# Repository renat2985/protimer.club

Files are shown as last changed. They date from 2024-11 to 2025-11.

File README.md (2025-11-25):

[🇷🇺 Русская версия документации здесь](https://github.com/renat2985/protimer.club/blob/main/README_RU.md)

#  Your Personal Performance Archive!

**ProTimer.club** is a modern solution for athletes, offering precise time measurement, result recording, and analysis to enhance training efficiency. Our devices are suitable for various sports and competitions, providing convenience, accuracy, and cloud integration.

You can log in with a demo profile and explore all the website features right now: [https://protimer.club/login#demo](https://protimer.club/login#demo)

    Email: demo@protimer.club
    Password: demo 

Here’s a link showcasing how you can share your page and display your results to anyone, even those who are not registered on the site: https://protimer.club/share/MzlLRDlaT1hnMTNaeEVZbnFSTTNHUT09

<p align="center">
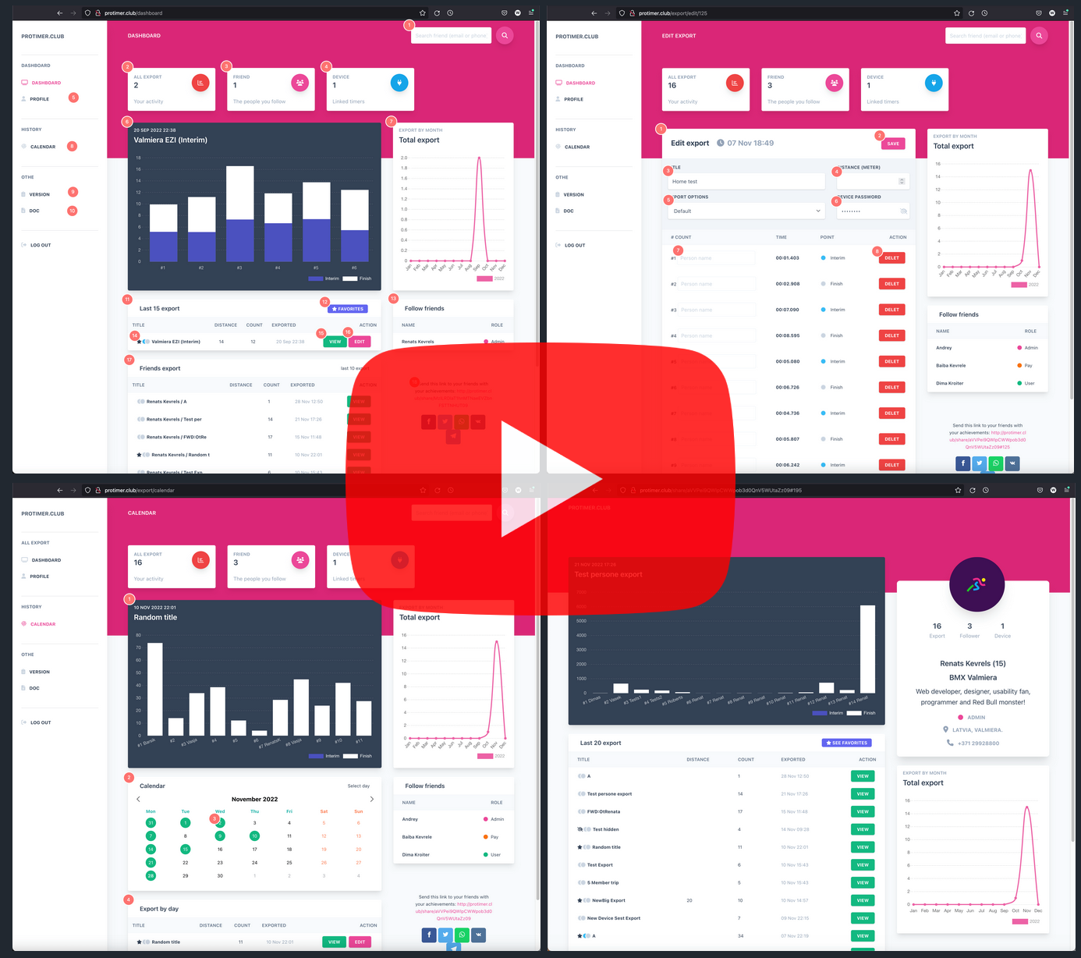
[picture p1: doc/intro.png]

</p>

## Key Features

  - **Precise time measurement:** Accuracy up to 0.003 seconds.
  - **Ease of use:** Simple system setup accessible to everyone.
  - **Cloud integration:** Export data to ProTimer.club for storing and analyzing training history.
  - **Social network:** Share achievements and follow the progress of your friends.
  - **Versatility:** Support for various modes and features for team and individual training.

_Learn more about the features [here](https://protimer.club/en/doc)._

---

## How It Works

### Master Point — The main module of the system that manages the ProTimer network.

1. **Power On and Connect:**

    - Turn on the Master Point; it will create a Wi-Fi network "ProTimer.club".
    - Connect to this network using your smartphone, tablet, or laptop.

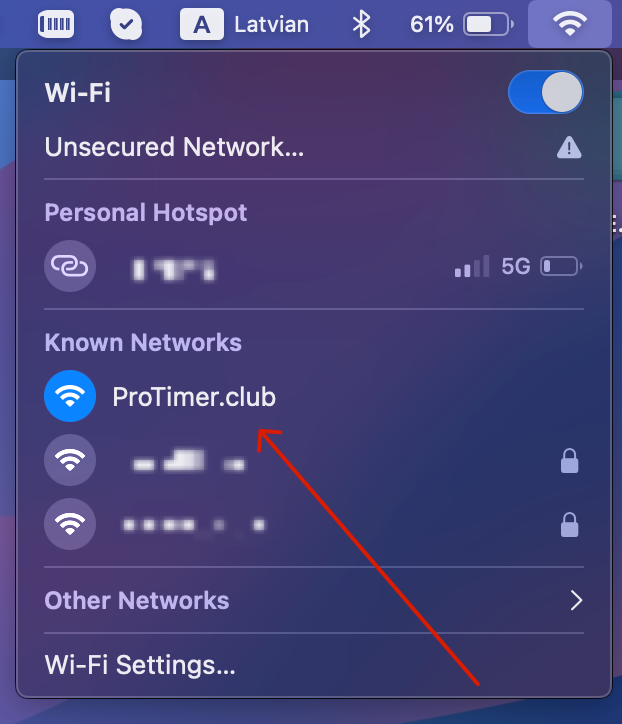
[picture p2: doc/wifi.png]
        

2. **Access the Control Interface:**

    - Open a browser and enter the address `http://192.168.4.1` to access the web interface.
    - Use the interface to configure modes, control the timer, and export data.

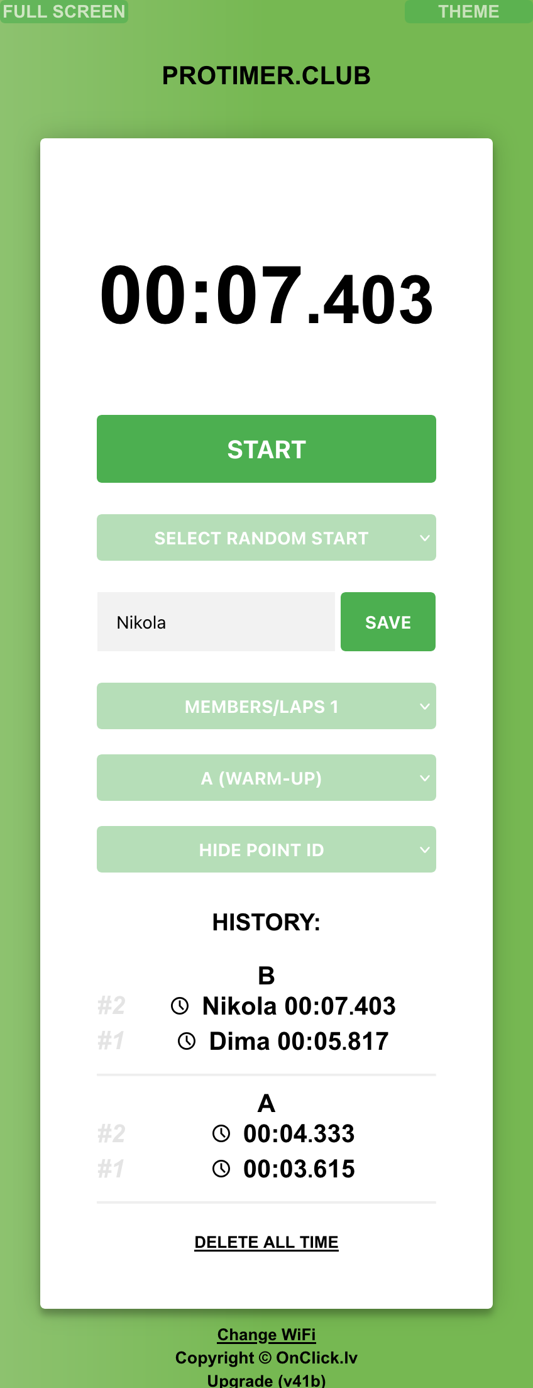
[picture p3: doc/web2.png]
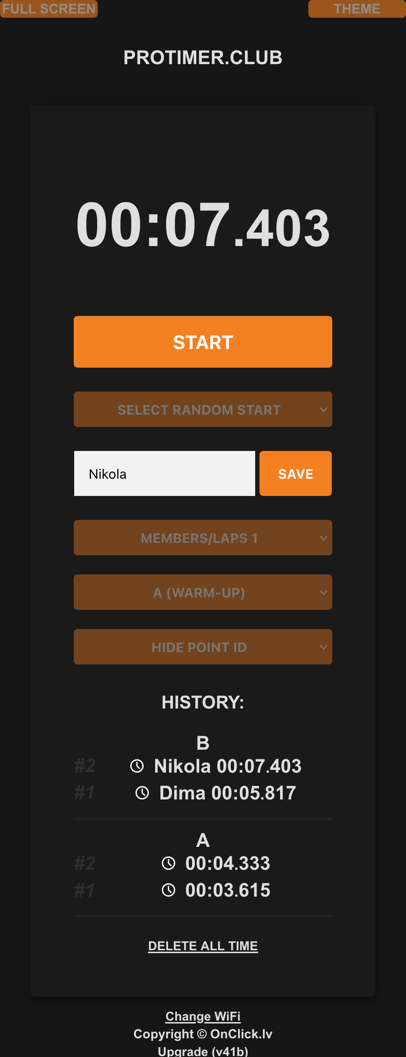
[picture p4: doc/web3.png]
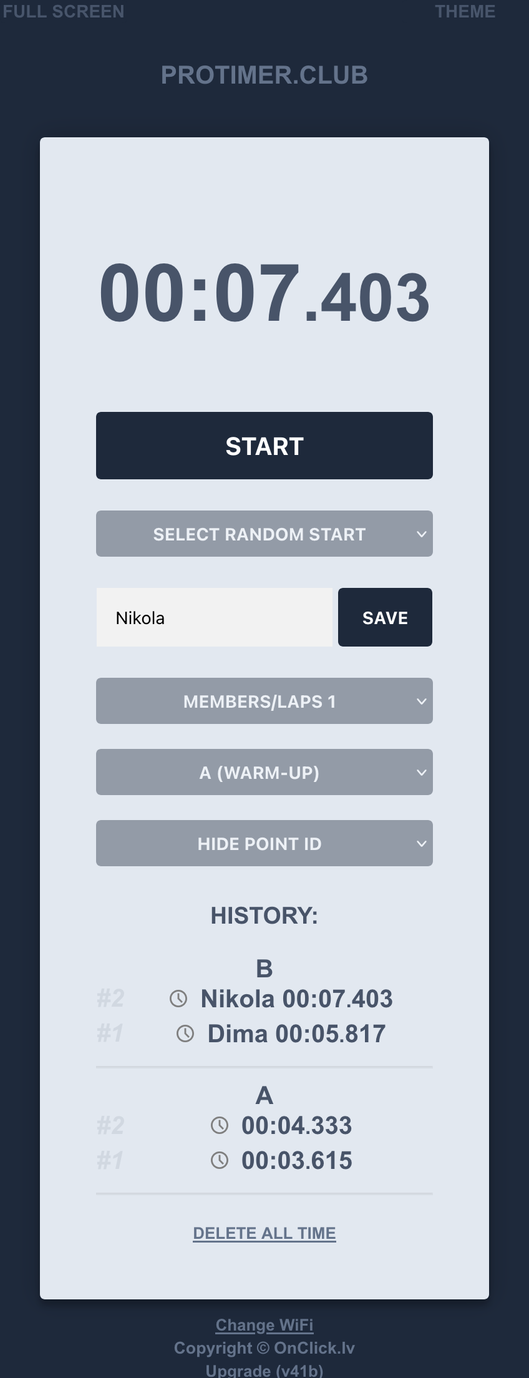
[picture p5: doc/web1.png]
          

3. **Connecting to the Router:**

    - During the first setup, the device will ask for your home Wi-Fi network name and password. This is required for automatic data export to the cloud.
    - Once configured, the device will automatically connect to the specified router every time it is powered on and upload your data to the ProTimer.club cloud.
    - This means that after your training session, you just need to turn on the device for a few seconds — it will connect to Wi-Fi and export all your results automatically. Simple and convenient!

    **Device Display:**

       

    _Read more details [here](https://protimer.club/en/doc#doc5)._

### Point PRO — An additional module that serves as a start, intermediate, or finish point.

1. **Operating Modes:**

    - **Start:** Starts the timer when the beam between the sensor and the reflector is crossed.
    - **Intermediate:** Captures split times at intermediate points.
    - **Finish:** Stops the timer when the beam is crossed.

2. **Connection to Master Point:**

    - Point PRO automatically synchronizes with Master Point within a range of up to 250 meters.
    - Use the built-in Point PRO display to check the connection and select the operating mode.

3. **Point PRO Features:**

    - Equipped with a display for real-time status updates.
    - Supports multiple channels for simultaneous use of multiple sets on one track.
    - High measurement accuracy of up to 0.003 seconds.

    **Device Display:**

      

    _Read more details [here](https://protimer.club/en/doc#doc5)._

#### ⚠️ Point PRO and Master Point work together, giving athletes and coaches full control over training sessions with precise results.

---

## Contact

You can build the device yourself or ask us to do it for you. To order a ready-made device, contact us via [Telegram](https://t.me/ESPiotDevice), [WhatsApp](https://chat.whatsapp.com/H7IpCrilF00H3wGbANnA1i), [Skype](https://skype:renat2985?chat), or [Discord](https://discord.gg/3986vwEdf5).

Ready-made equipment kits with customization options and additional modules are also available on our website.

---

## Connection Diagram

You can build the device using NodeMCU ESP8266 or Wemos ESP8266. This diagram applies to both the Master and Point (PRO) devices. Choose the appropriate software link below for installation.

On the NodeMCU board, the Flash button performs the same functions as the external button connected to D3. If needed, you can use it instead of the external button.

## Pinout Configuration

| **Pin** | **GPIO** | **Function** |
|---|---|---|
| **D1**  | GPIO5 | SCK (Display) |
| **D2**  | GPIO4 | SDA (Display) |
| **RX**  | GPIO3 | IR or LASER Sensor (NPN NO)|
| **D3**  | GPIO0 | Button |
| **D7**  | GPIO13 | Active Buzzer (optional) |
| **D6**  | GPIO12 | Passive Buzzer (optional)  |
| **D0**  | GPIO16 | [GATE Relay](https://github.com/renat2985/protimer.club/discussions/6) (optional) |

### [E3Z-R61, NPN NO](https://www.aliexpress.com/item/1005004123351251.html) (max 2-3m "gates", IR sensor)

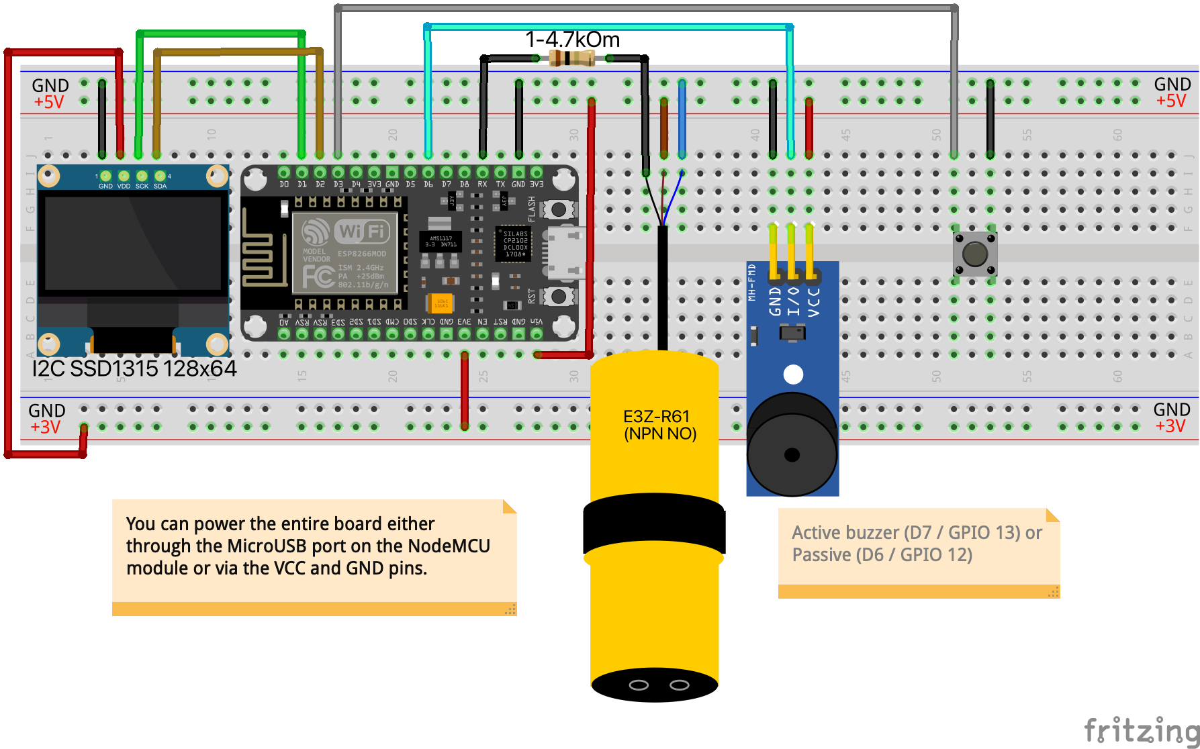
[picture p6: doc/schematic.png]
Connection Diagram
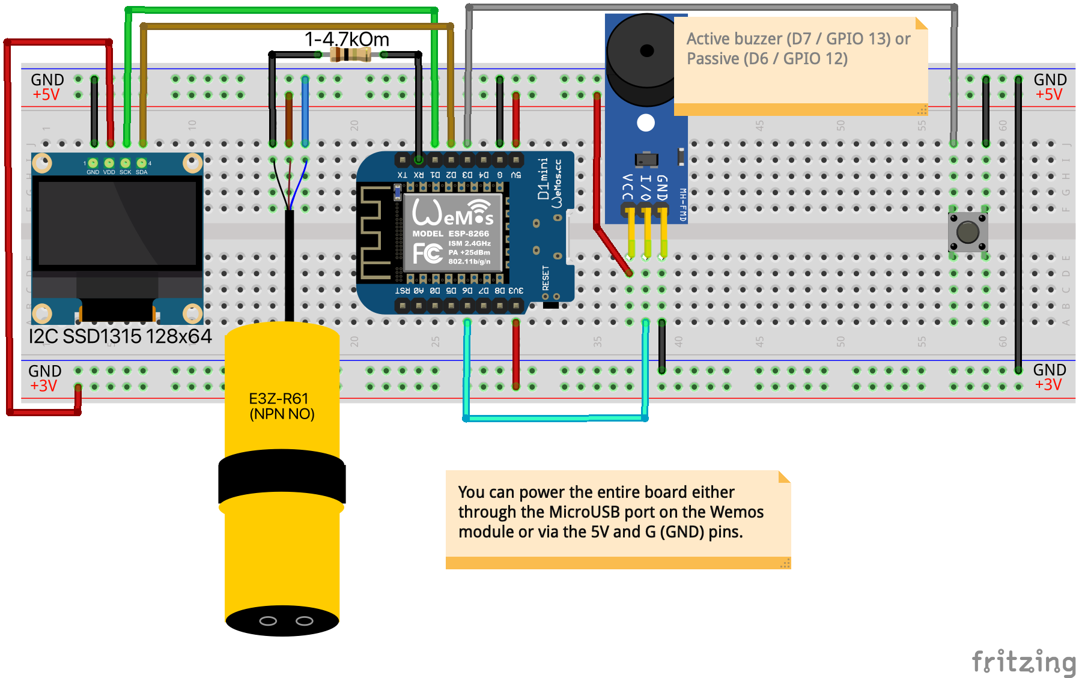
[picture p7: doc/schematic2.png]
Connection Diagram 2
 

### [E3Z-LAS-R8, NPN NO](https://www.aliexpress.com/item/1005005879848648.html) (max 7-8m "gates", Laser sensor) 

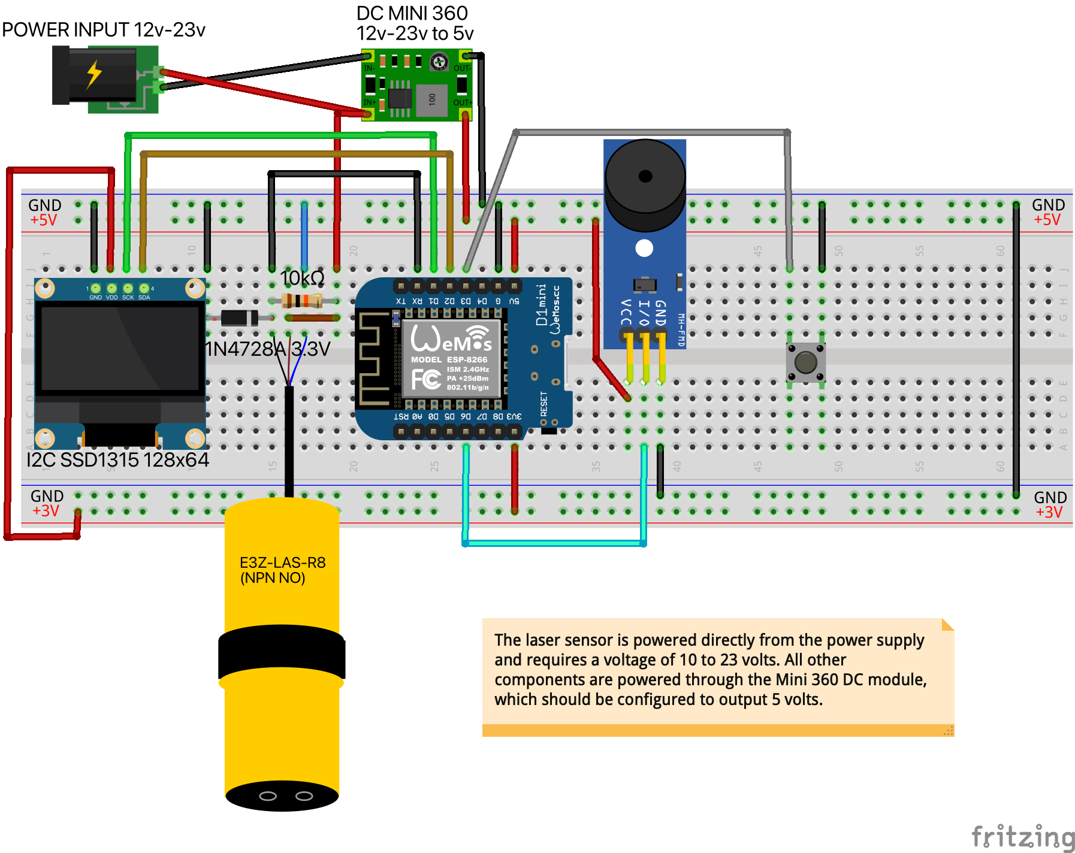
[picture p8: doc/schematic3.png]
Connection Diagram 3
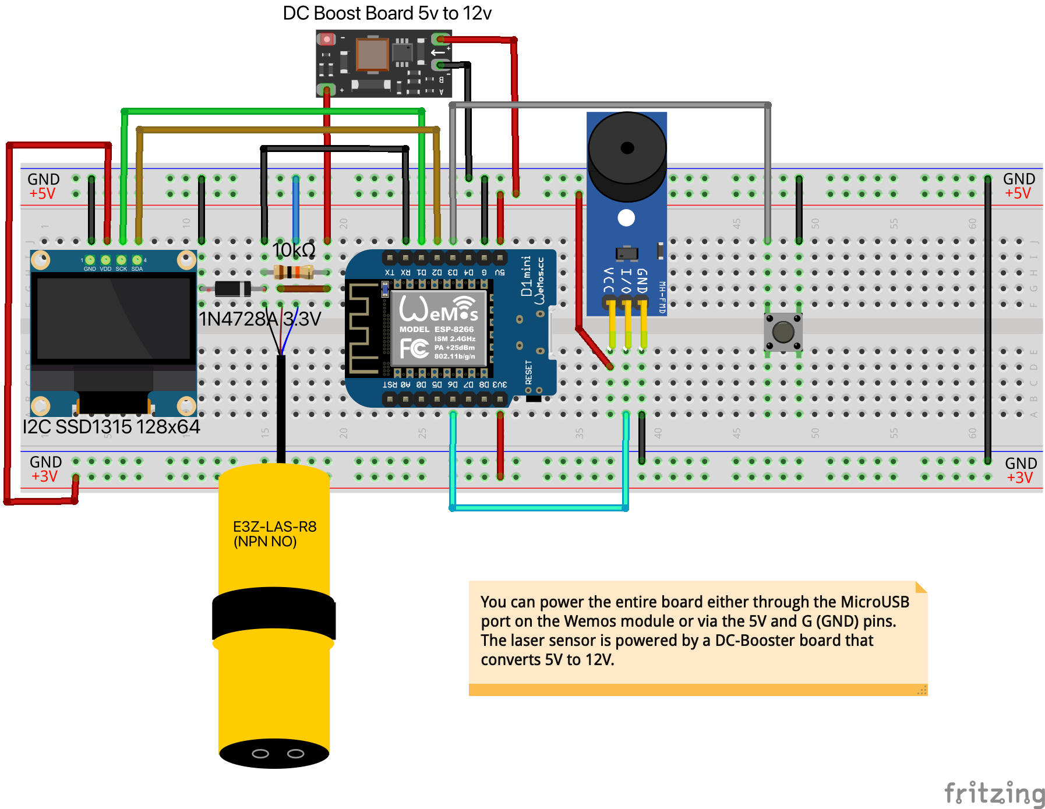
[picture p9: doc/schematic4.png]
Connection Diagram 4
 

## [Soldering Wemos, step by step](https://github.com/renat2985/protimer.club/discussions/10)

E3Z-R61

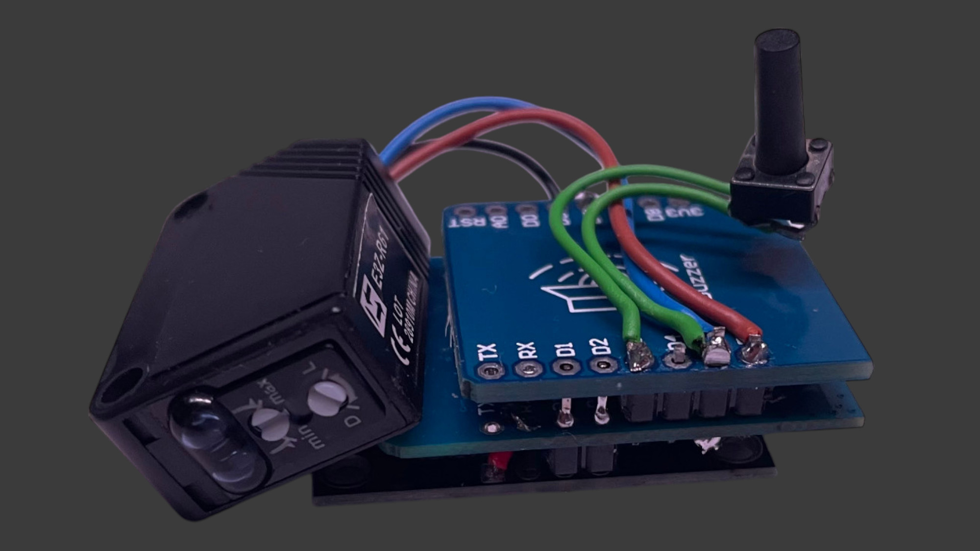
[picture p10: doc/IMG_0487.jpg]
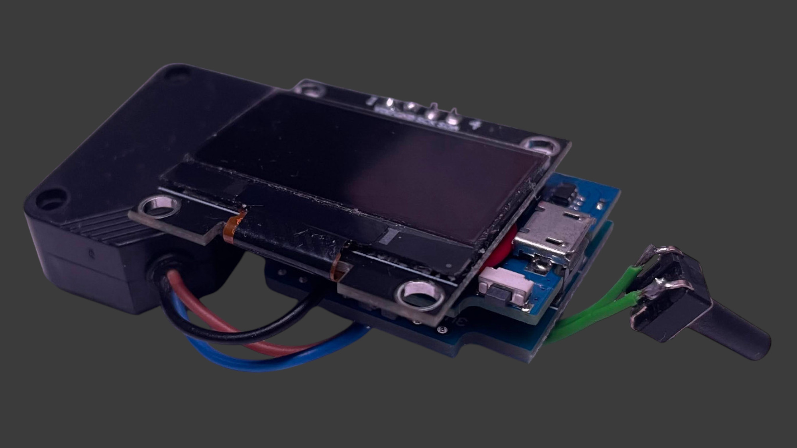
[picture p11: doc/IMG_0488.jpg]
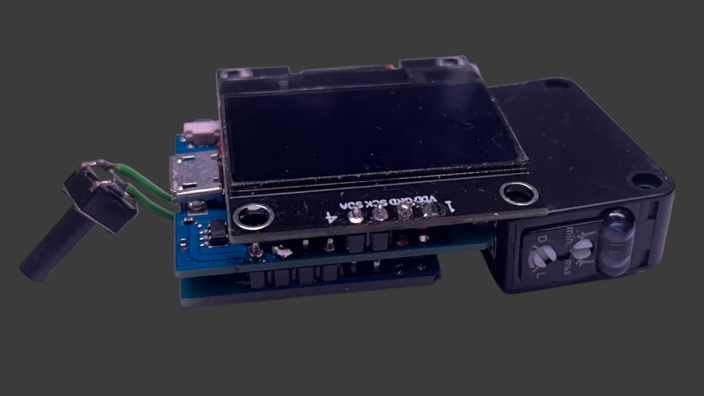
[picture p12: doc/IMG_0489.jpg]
  

E3Z-LAS-R8, NPN NO

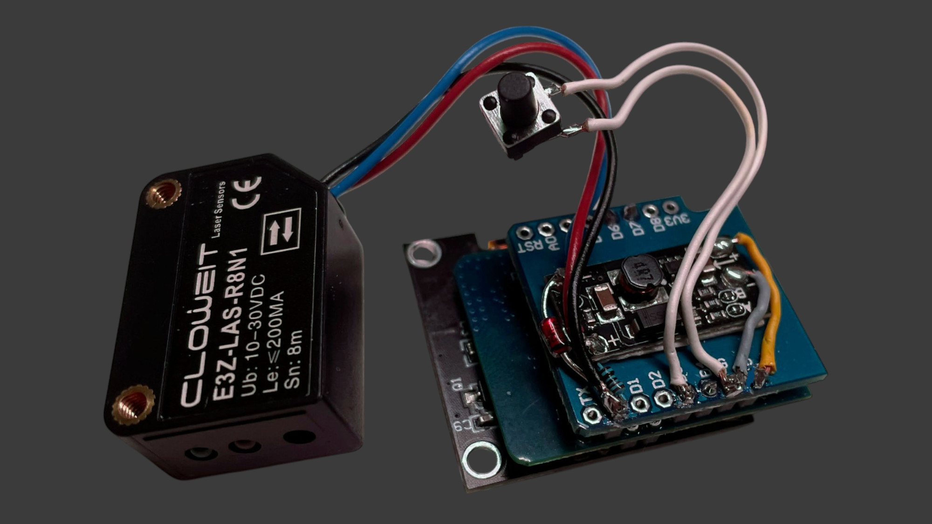
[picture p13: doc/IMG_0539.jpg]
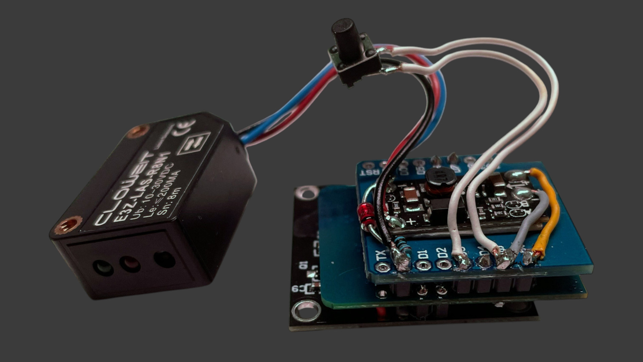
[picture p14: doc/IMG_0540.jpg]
 

## STL (STL Folder)

All these parts can be found and printed from the [stl folder](https://github.com/renat2985/protimer.club/tree/main/stl).

#### For IR Device: 
- [Cover Master](https://github.com/renat2985/protimer.club/blob/main/stl/%D1%81over-M-wemos-final-v3.stl), [Cover Point](https://github.com/renat2985/protimer.club/blob/main/stl/%D1%81over-P-wemos-final-v3.stl), [Box](https://github.com/renat2985/protimer.club/blob/main/stl/box-Laser-big-wemos-final-v3.stl).
- Design by Sergey K.: [Box and Cover(M)](https://github.com/renat2985/protimer.club/blob/main/stl/box_and_cover_M_by_SergeyKryzhkov.stl), 
[Box and Cover(P)](https://github.com/renat2985/protimer.club/blob/main/stl/box_and_cover_P_by_SergeyKryzhkov.stl).

#### For Laser Device: 
- [Cover Master](https://github.com/renat2985/protimer.club/blob/main/stl/%D1%81over-Laser-M-wemos-final-v3.stl), [Cover Point](https://github.com/renat2985/protimer.club/blob/main/stl/%D1%81over-Laser-P-wemos-final-v3.stl), [Box](https://github.com/renat2985/protimer.club/blob/main/stl/box-big-wemos-final-v3.stl).
- Design by Sergey K.: [Box and Cover(M)](https://github.com/renat2985/protimer.club/blob/main/stl/box_and_cover_Laser_M_by_SergeyKryzhkov.stl), 
[Box and Cover(P)](https://github.com/renat2985/protimer.club/blob/main/stl/box_and_cover_Laser_P_by_SergeyKryzhkov.stl).

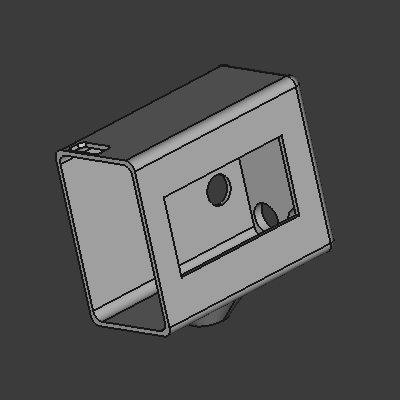
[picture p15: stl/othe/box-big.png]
Box big
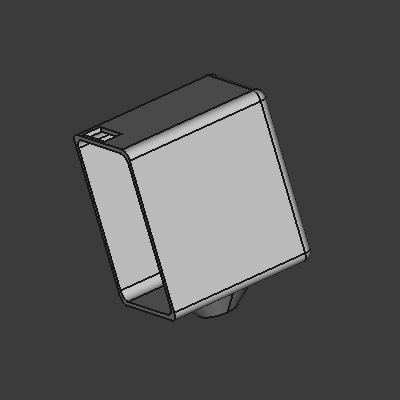
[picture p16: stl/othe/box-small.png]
Box small
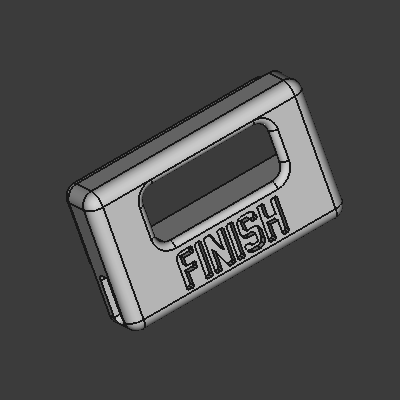
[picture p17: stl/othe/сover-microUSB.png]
Cover MicroUSB
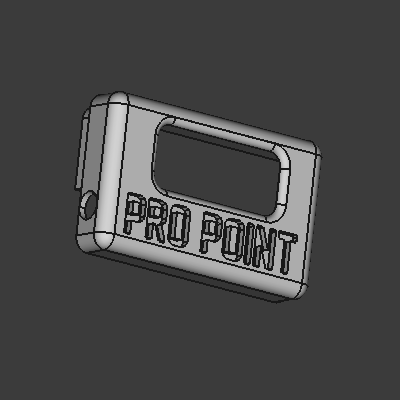
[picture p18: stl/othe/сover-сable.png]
Cover cable
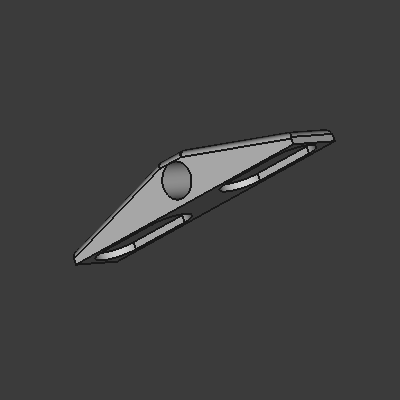
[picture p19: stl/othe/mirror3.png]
Reflector Holder 3
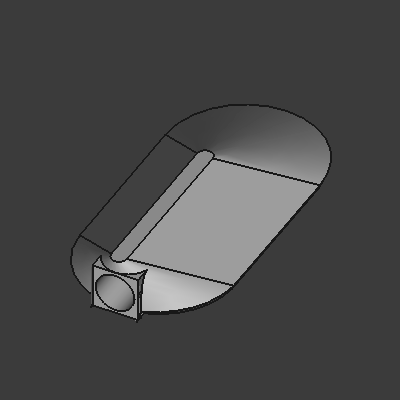
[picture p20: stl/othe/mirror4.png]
Reflector Holder 4
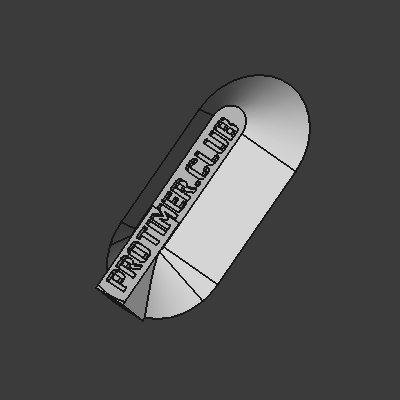
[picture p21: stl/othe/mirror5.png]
Reflector Holder 5
      

## From AliExpress.com

[E3Z-R61](https://www.aliexpress.com/item/1005004123351251.html) (2-3m, IR sensor) or [E3Z-LAS-R8, NPN NO](https://www.aliexpress.com/item/1005005879848648.html) (7-8m, Laser sensor) 

[Reflector TD-05](https://www.aliexpress.com/item/32990489226.html) (Better) or [Reflector TD-08](https://www.aliexpress.com/item/1005003584568763.html) (Worse)

[I2C SSD1315 128x64 1.3inch](https://www.aliexpress.com/item/1005004118377699.html)

[Wemos MINI ESP07](https://www.aliexpress.com/item/1005007081723288.html) (Suitable for STL case) or [NodeMCU ESP8266](https://www.aliexpress.com/item/1005004893349830.html) 

[Push Button Switch](https://www.aliexpress.com/item/1005004159746274.html) (6x6x8mm)

[Passive Buzzer Shield for WEMOS (D6 gpio)](https://www.aliexpress.com/item/1005007463046770.html) or [Active Buzzer Module for Arduino (D7 gpio)](https://www.aliexpress.com/item/1005005528181661.html)

Components for E3Z-LAS-R8, NPN NO

[Step-Down Board Mini 360](https://www.aliexpress.com/item/1005005995617482.html)

[Mini DC Boost Converter Board](https://www.aliexpress.com/item/1005007013856492.html)

[1N4728A 3.3V Zener Diode](https://www.aliexpress.com/item/4000297831644.html)

Other components 

[NFC Tag (NFC213, NFC215, NFC216)](https://www.aliexpress.com/item/1005002932627448.html)

[WiFi Antenna / IPEX Connector)](https://www.aliexpress.com/item/1005005743897181.html)

[Power Bank for 18650 Battery](https://www.aliexpress.com/item/1005002367815544.html)

[Mini Flexible Sponge Octopus Tripod](https://www.aliexpress.com/item/1005004177317958.html)

---

### 🚀 **Web Installer (Recommended)**  
Easily set up your device using the web installer. Choose the appropriate version and follow the instructions.

- **[Master Installer](https://renat2985.github.io/protimer.club/):** The main device that records the time.  
- **[Point Installer](https://renat2985.github.io/protimer.club/point.html):** An additional device that marks the finish line, checkpoints, or the start.  

### 🚀 **ESP8266 NodeMCU Flasher** 
- **[Download Installer](https://github.com/renat2985/protimer.club/raw/refs/heads/main/build/protimer.club.zip):** The archive contains two firmware versions: Master and Point.
    - To flash the Master version, check the box for upgrade128x64.bin.
    - To flash the Point version, uncheck upgrade128x64.bin and check upgrade_point128x64.bin.

    ❗ Important: You cannot check two boxes at the same time!

---

Instructions for users:

[DPF instructions (RUS)](https://github.com/renat2985/protimer.club/blob/main/doc/instruction.pdf)

[https://protimer.club/install/0000-0000](https://protimer.club/install/0000-0000) - you can change the WiFi password.

[https://protimer.club/install/en/0000-0000](https://protimer.club/install/ru/0000-0000) - you can change the language and the WiFi password.

---

### Acknowledgements
I would like to express my sincere gratitude to everyone who contributed to the project with their time, knowledge, and support. Thanks to you, it keeps getting better:
- Alex K.
- Sergey K.

## :battery: Donation

If you like this project, you can support us by buying a cup of coffee! ☕  

Donate Image

- **PayPal:** [https://www.paypal.me/RKevrels](https://www.paypal.me/RKevrels/5)

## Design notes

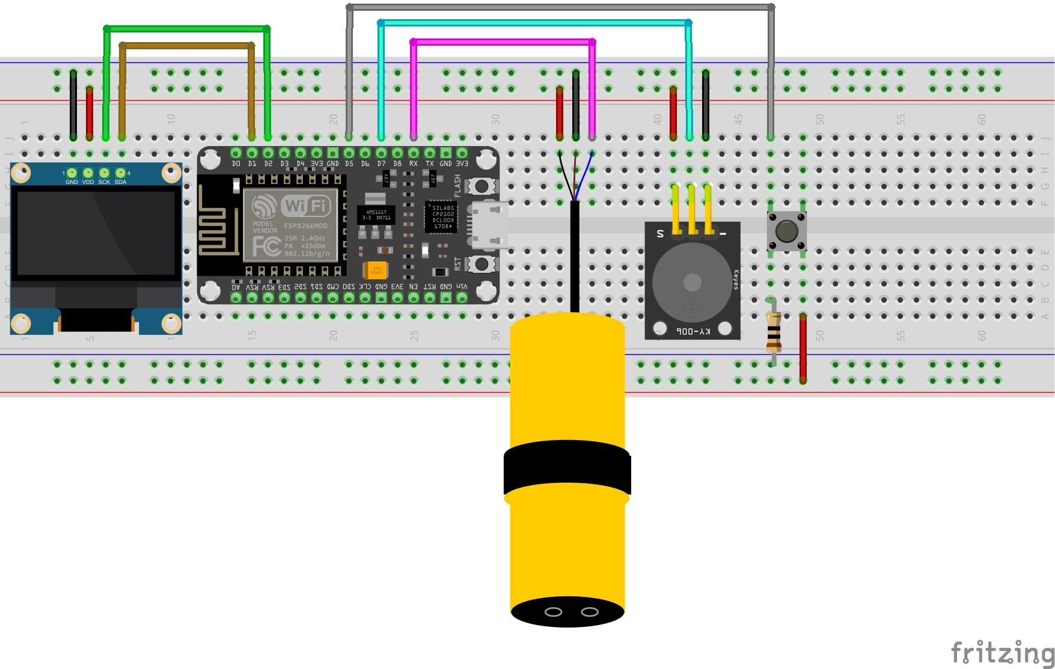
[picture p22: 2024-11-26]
docs/schematic.png

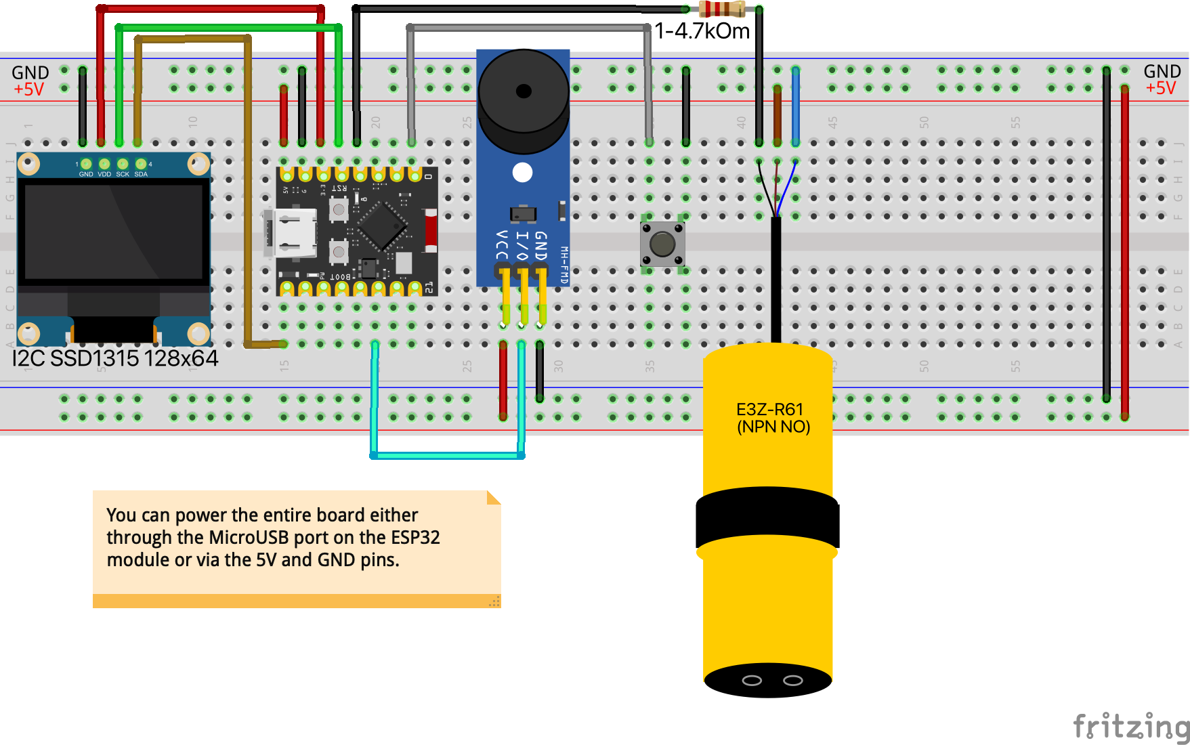
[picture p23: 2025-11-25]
doc/schematic5.png

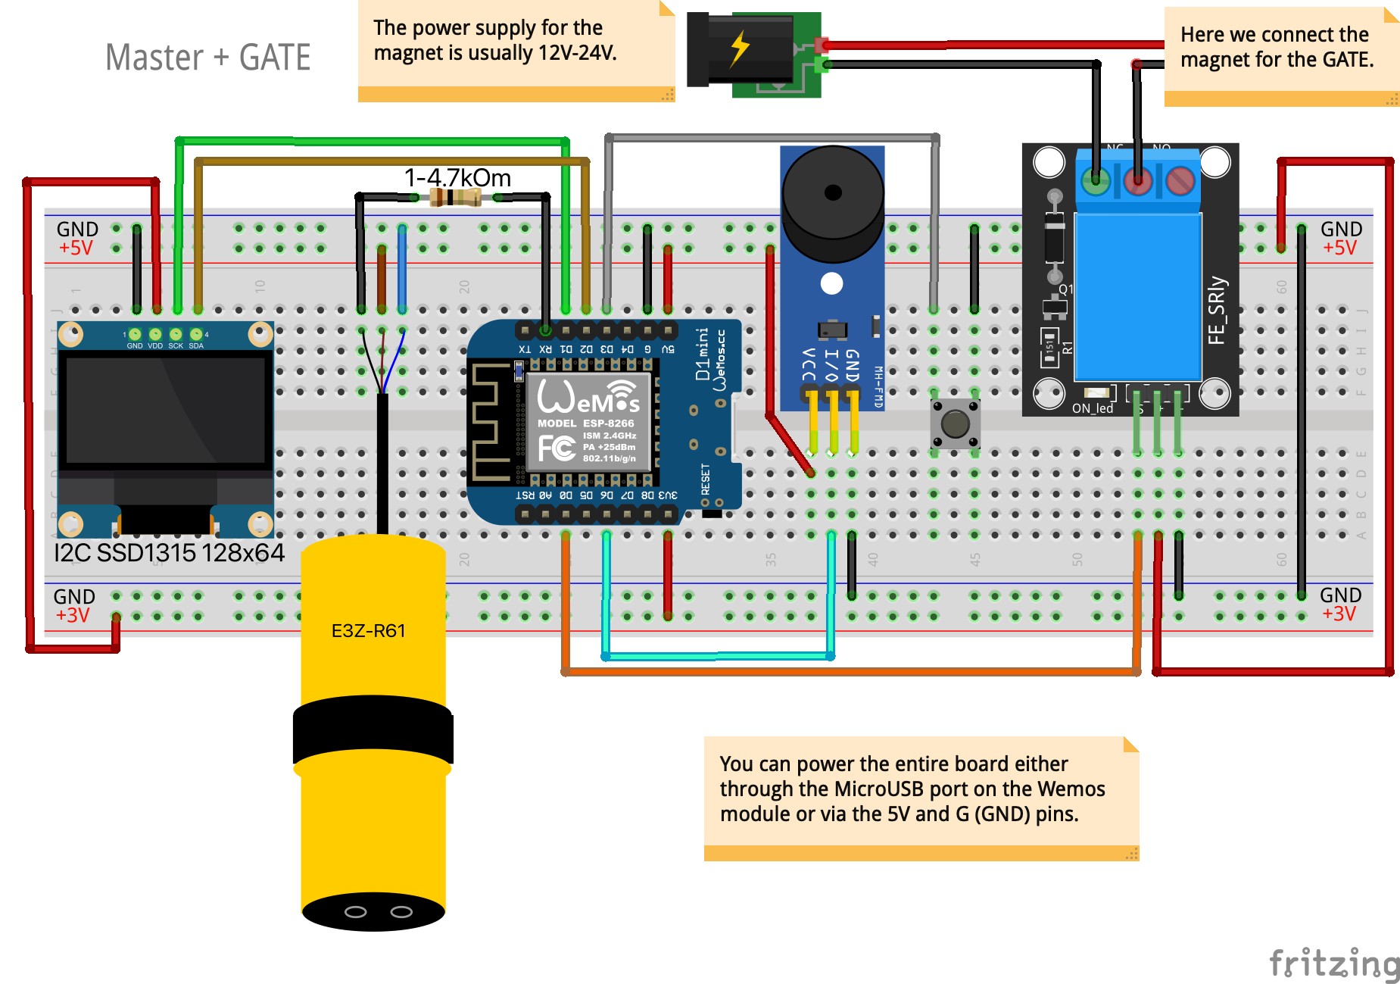
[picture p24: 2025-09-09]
doc/schematic2_gate.png

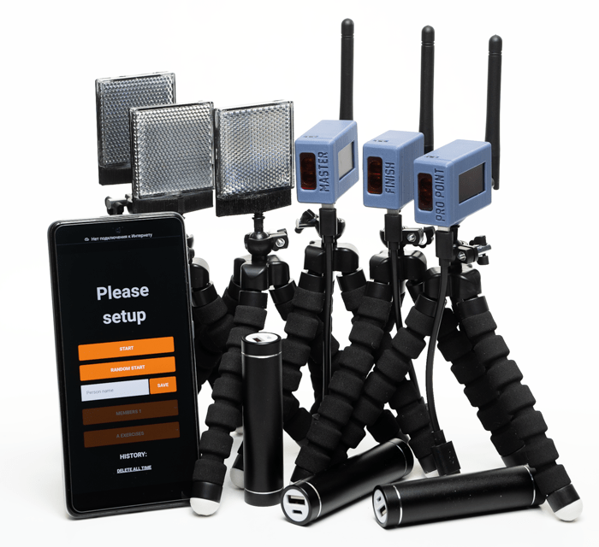
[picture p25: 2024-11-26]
doc/protimer2.png

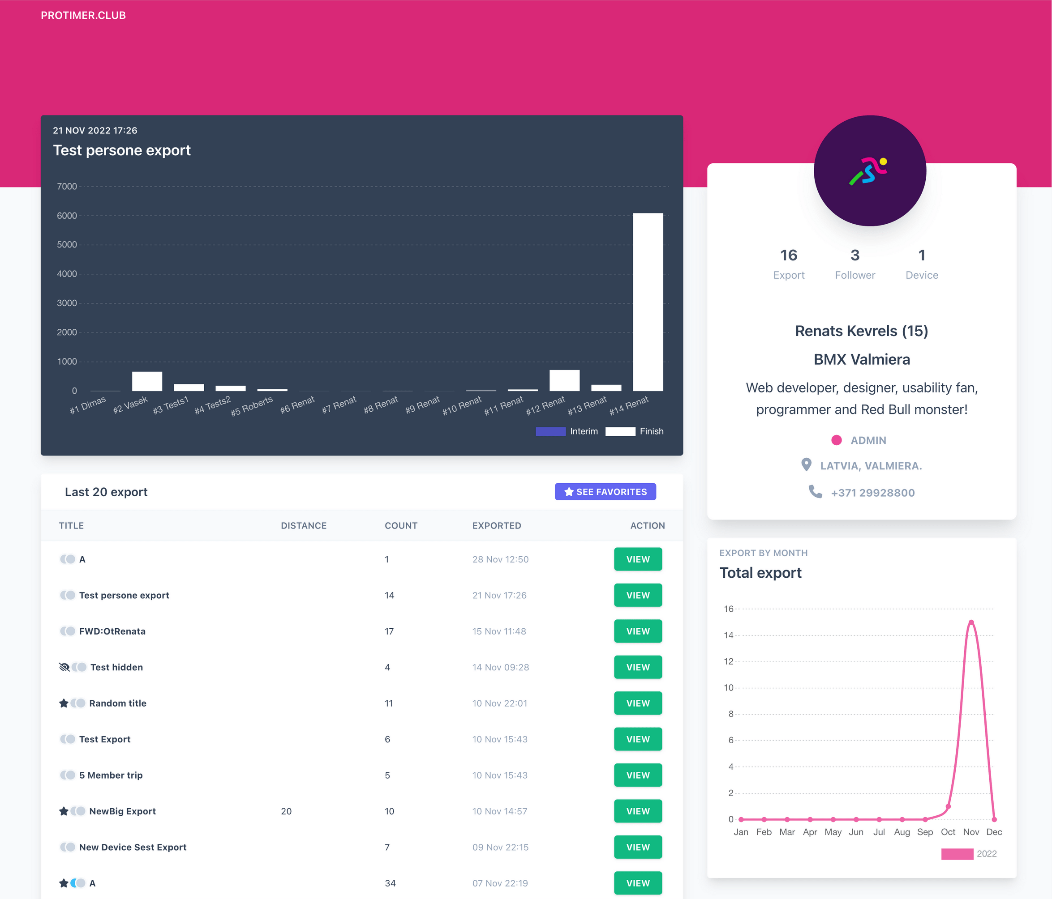
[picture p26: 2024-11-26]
docs/protimer3.png

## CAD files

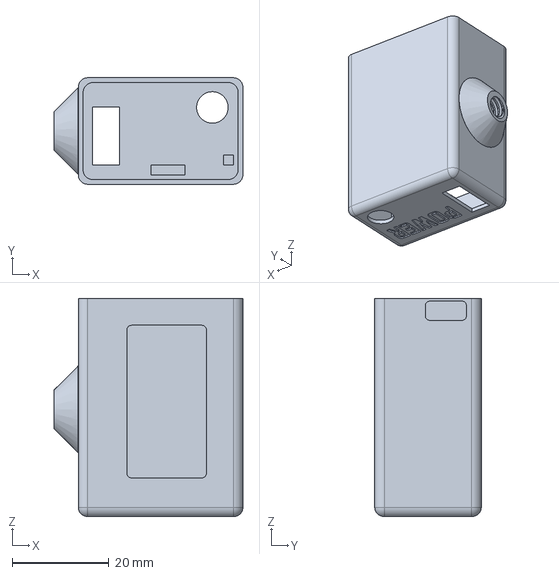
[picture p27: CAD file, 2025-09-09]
stl/othe/box-big-final-custom-type-c.FCStd
39.0 x 22.0 x 45.0 mm

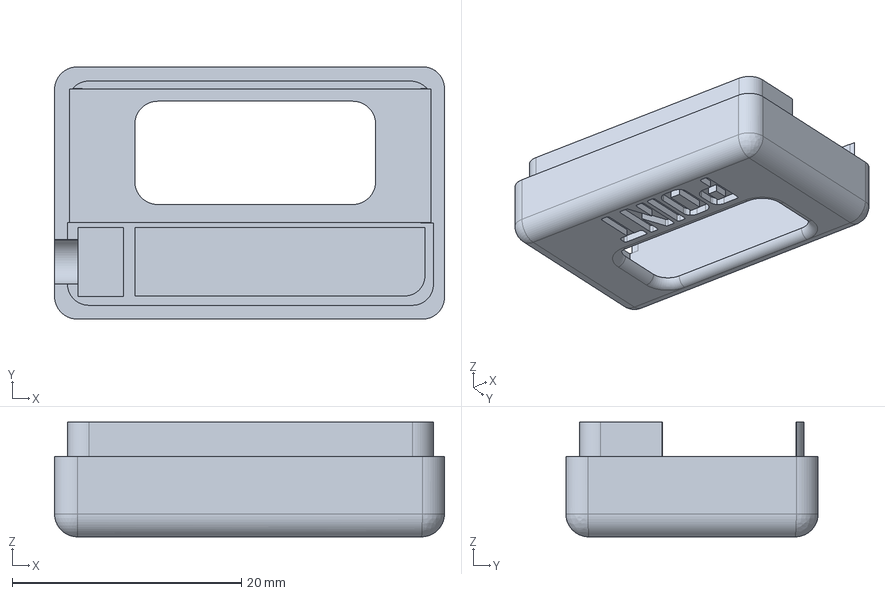
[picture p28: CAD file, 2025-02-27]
stl/сover-Laser-P-wemos-final-v3.FCStd
34.0 x 22.0 x 10.0 mm

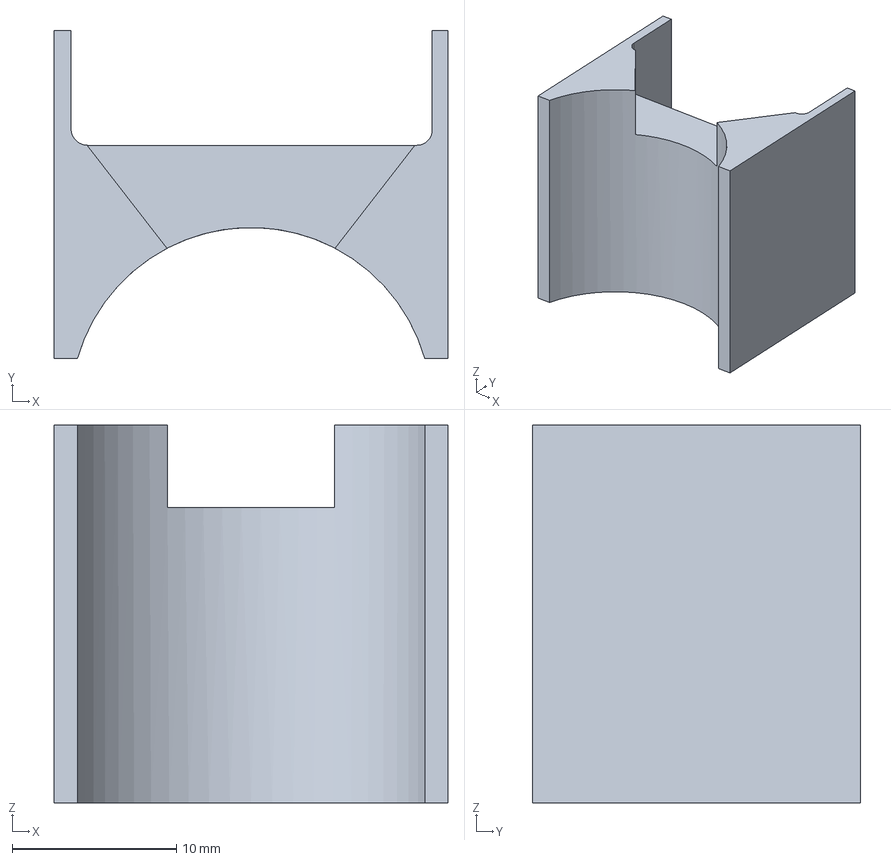
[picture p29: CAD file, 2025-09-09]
stl/othe/powerbankbox.FCStd
24.0 x 20.0 x 23.0 mm

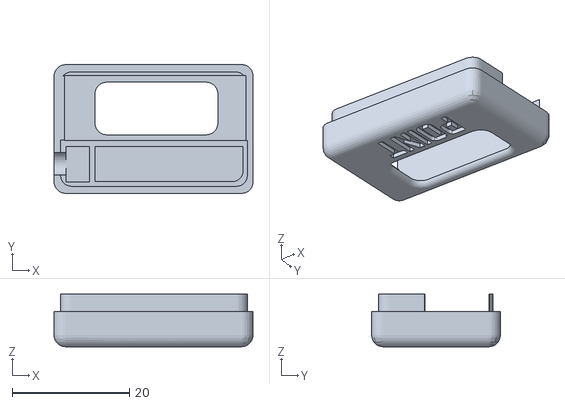
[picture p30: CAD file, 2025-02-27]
stl/сover-P-wemos-final-v3.stl
34.0 x 22.0 x 9.00

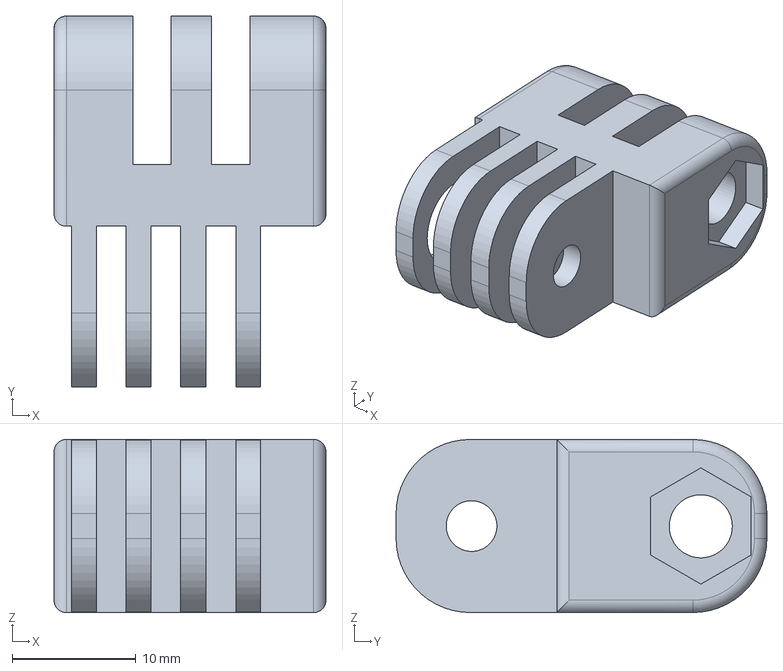
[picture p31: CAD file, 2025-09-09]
stl/othe/tripod-connector-big.FCStd
22.0 x 30.0 x 14.0 mm

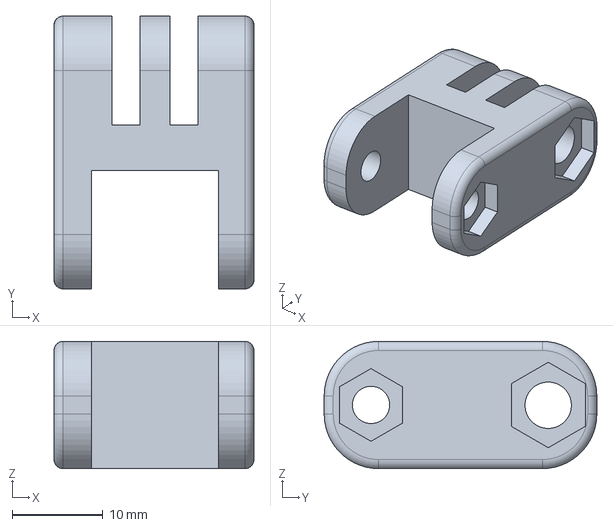
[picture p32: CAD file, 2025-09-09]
stl/othe/tripod-connector.FCStd
22.0 x 30.0 x 14.0 mm

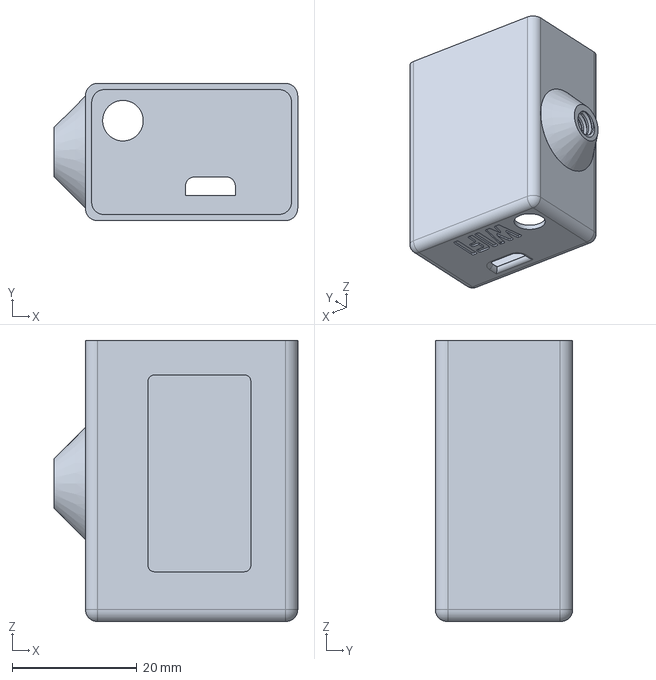
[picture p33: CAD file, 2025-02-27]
stl/box-Laser-big-wemos-final-v3.FCStd
39.0 x 22.0 x 45.0 mm

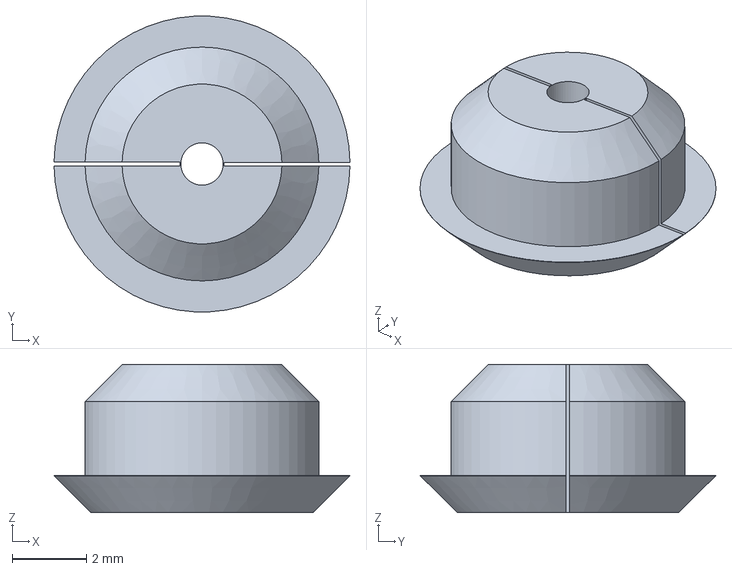
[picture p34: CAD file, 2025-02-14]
stl/plug-v3.FCStd
8.00 x 7.99 x 4.00 mm

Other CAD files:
stl/сover-Laser-M-wemos-final-v3.stl
stl/сover-Laser-wemos-final-v3.FCStd
stl/othe/box-big-final-custom-v2.FCStd
stl/сover-wemos-final-v3.FCStd
stl/othe/box-big-final8-custom-v8.stl
stl/сover-M-wemos-final-v3.stl
stl/othe/box-big-final7-custom-v7.stl
stl/box-big-wemos-final-v3.FCStd
stl/othe/box-big-wemos-final-v2.FCStd
stl/othe/сover-wemos-final-v2.FCStd
stl/box-Laser-big-wemos-final-v3.stl
stl/box-big-wemos-final-v3.stl
stl/mirror3.FCStd
stl/mirror3.stl
stl/mirror4.FCStd
stl/mirror4.stl
stl/mirror5.FCStd
stl/mirror5.stl
stl/othe/box-big-final-custom-type-c.stl
stl/othe/box-big-final-custom-v2.stl
stl/othe/box-big-final-custom.FCStd
stl/othe/box-big-final-custom.stl
stl/othe/box-big-wemos(no hole buzzer).FCStd
stl/othe/box-big-wemos(no hole buzzer).step
stl/othe/box-big-wemos(no hole buzzer).stl
stl/othe/box-big-wemos-final-v2.stl
stl/othe/box-big-wemos-final.FCStd
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

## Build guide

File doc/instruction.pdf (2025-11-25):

Инструкция
1. Включите изделие «Master» (на крышке буква «М») - (подсоедините повербанк к проводу);
2. Выберите на экране (нажатием кнопки) один из режимов:
Режим | Описание
Master mode | модуль работает как Стартовая точка, может быть размещен в начале дистанции, секундомер запускается пересечением луча между фотоэлементами.
Gate mode | решение для старта гонки на время с любым барьером. Master-устройство устанавливается перед любым барьером на расстояние до 10 см., без необходимости в зеркале. Когда барьер опускается, устройство фиксирует это и автоматически запускает таймер.
Gate AUX mode | модуль оснащен AUX-выходом для подключения электромагнитного барьера DIY. С помощью WEB-интерфейса ProTimer.club у вас будет возможность использовать "Random Start"- со звуковым отсчетом. В этом режиме возможно определить реакцию участника после звуковой команды «Старт».
Display mode | модуль работает как дисплей, встроенный датчик отключен, его можно носить с собой. Вам понадобится модуль «Point» в режиме «Start point» для запуска времени или можно управлять через ВЕБ-интерфейс.
Laps mode | режим, в котором не нужны дополнительные поинты: встроенный сенсор мастер-поинта работает как финиш поинт. Вы выбираете количество кругов в приложении и запускаете таймер вручную. Каждый раз, пробегая мимо мастер-поинта, система засчитывает круг. В конце отображается общее время забега.
3. Выставляем «Зеркало» на расстояние от 8 до 4 метров, получаем «Ворота фиксации участника», при правильной настройке идет звуковое сопровождение;
4. Через смартфон (ноутбук) подключаемся к точке Wi-Fi с наименованием «ProTimer.club» и паролем «1860-7052», в любом браузере переходим на страницу по адресу «http://192.168.4.1» 1 Переключиться в полноэкранный режим.
2 Переключение между темами визуализации.

### 3 Секундомер в реальном времени, вы можете следить за

длительностью дистанции как в WEB-приложении, так и на дисплее Master Point.
4 Кнопка "Start", ручной запуск таймера, если таймер работает, его можно остановить, вместо "Start" будет кнопка "Stop".

### 5 Кнопка для стандарта UCI Random Gate Start. Выход AUX

можно использовать для подключения электромагнитного барьера DIY.

### 6 Идентификатор спортсмена (имя, номер...) должен быть

сохранен до того, как сработает точка финиша, актуально в групповых занятиях, время с идентификатором будет доступно в облаке ProTimer.club после экспорта.

### 7 Также актуальна для групповых занятий. Финишная точка

будет работать для выбранного количества участников.

### 8 Возможность разделить урок по упражнениям, по экспорту, в

облаке ProTimer.club, каждому графику упражнений можно дать свое имя.
9 Время, в конце дистанции "Finish", упражнение А.
10 Время, в упражнении на промежуточную точку А.
11 Удалить все записи, очистить историю.

### 12 Изменить настройки точки доступа, через которую Мастер-

точка будет загружать (экспортировать).

### 13 Обновление программного обеспечения Master Point и

текущая версия.

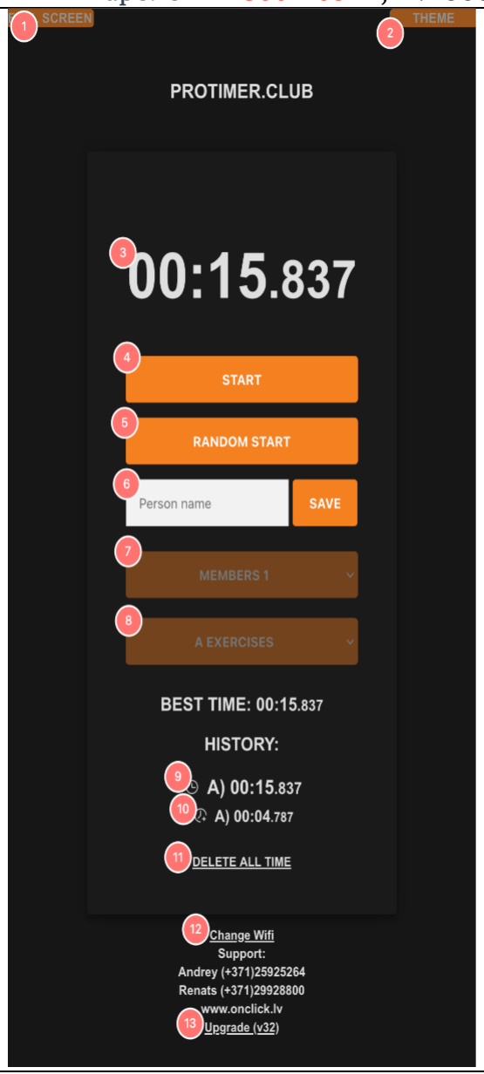
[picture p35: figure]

5. Включите изделие «Point» (на крышке буква «Р») – (подсоедините повербанк к проводу);
6. Выберите на экране (нажатием кнопки) один из режимов:
Режим | Описание
Start point | модуль работает как Стартовая точка, может быть размещен в начале дистанции, секундомер запускается пересечением луча между фотоэлементами.
Interim point | модуль работает как Промежуточная точка, может быть размещен в любом точке на дистанции, секундомер «отсекает» фиксирует время от старта до пресечение луча между фотоэлементами.
St.+Int. point | модуль работает как Стартовая точка, так и Промежуточная точка.
Gate point | решение для старта гонки на время с любым барьером. Point-устройство устанавливается перед любым барьером на расстояние до 10 см., без необходимости в зеркале. Когда барьер опускается, устройство фиксирует это и автоматически запускает таймер (Старт без звукового сопровождения)
Finish point | модуль работает как Финишная точка, так же в ВЕБ-интерфейсе на смартфоне можно выставить количество участников (количество сработок Point-устройство как Финишь).
7. Выставляем «Зеркало» на расстояние от 8 до 4 метров, получаем «Ворота фиксации участника», при правильной настройке идет звуковое сопровождение;
8. Выставляем Время, в течение которого датчик не будет снова реагировать на прерывание луча, это время можно изменить, нажав кнопку, мин.: 0,10 с, макс.: 2,50 с. По умолчанию: 0,1с.

Примечание:
- На дисплее устройства «Master» Вы можете просмотреть последние 20 записей, нажав кнопку на устройстве.
- Перед использованием устройств проверти зараженность повербанков.

Описание:
ProTimer.club — это современное решение для спортсменов, позволяющее с высокой точностью измерять время, регистрировать результаты и анализировать их для повышения эффективности тренировок. Наши устройства подходят для различных видов спорта и соревнований, предоставляя пользователям удобство, точность измерения — до 0,003 секунды.

Примеры установки датчиков: БЕГ 100 метров
ОДИН Участник:
(датчики: «Мастер» запускается в режиме «Master mode»; «Поинт» - «Finish point»)

рефлектор –
датчика

рефлектор –
датчика
10-15 см

Линия СТАРТА

Линия луча датчика
Линия ФИНИША

10-15 см
датчик LS
«МАСТЕР» -
Режим
«Master mode»

Датчик LS
«ПОИНТ» -
Режим
«Finish point»

ДВА Участника:
(датчики: «Мастер» запускается в режиме «Master mode»; «Поинт» - «Interim point»)

рефлектор –
датчика

рефлектор –
датчика
10-15 см

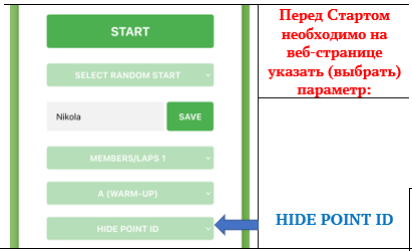
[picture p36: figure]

Линия СТАРТА

Линия луча датчика
Линия ФИНИША

(сеундомер останавливается на веб-странице кнопкой «СТОП»)

датчик №2 IR
«ПОИНТ» -
Режим
«Interim point»
рефлектор –
датчика

10-15 см
датчик LS
«МАСТЕР» -
Режим
«Master mode»

Датчик LS
«ПОИНТ» -
Режим
«Interim point»

БЕГ 10 Х 10 метров
ДВА Участника:
(датчики: «Мастер» запускается в режиме «Laps mode»; «Поинт» - «ST.+INT. point»)

Линия СТАРТА и ФИНИША

(сеундомер останавливается на веб-странице кнопкой «СТОП»)

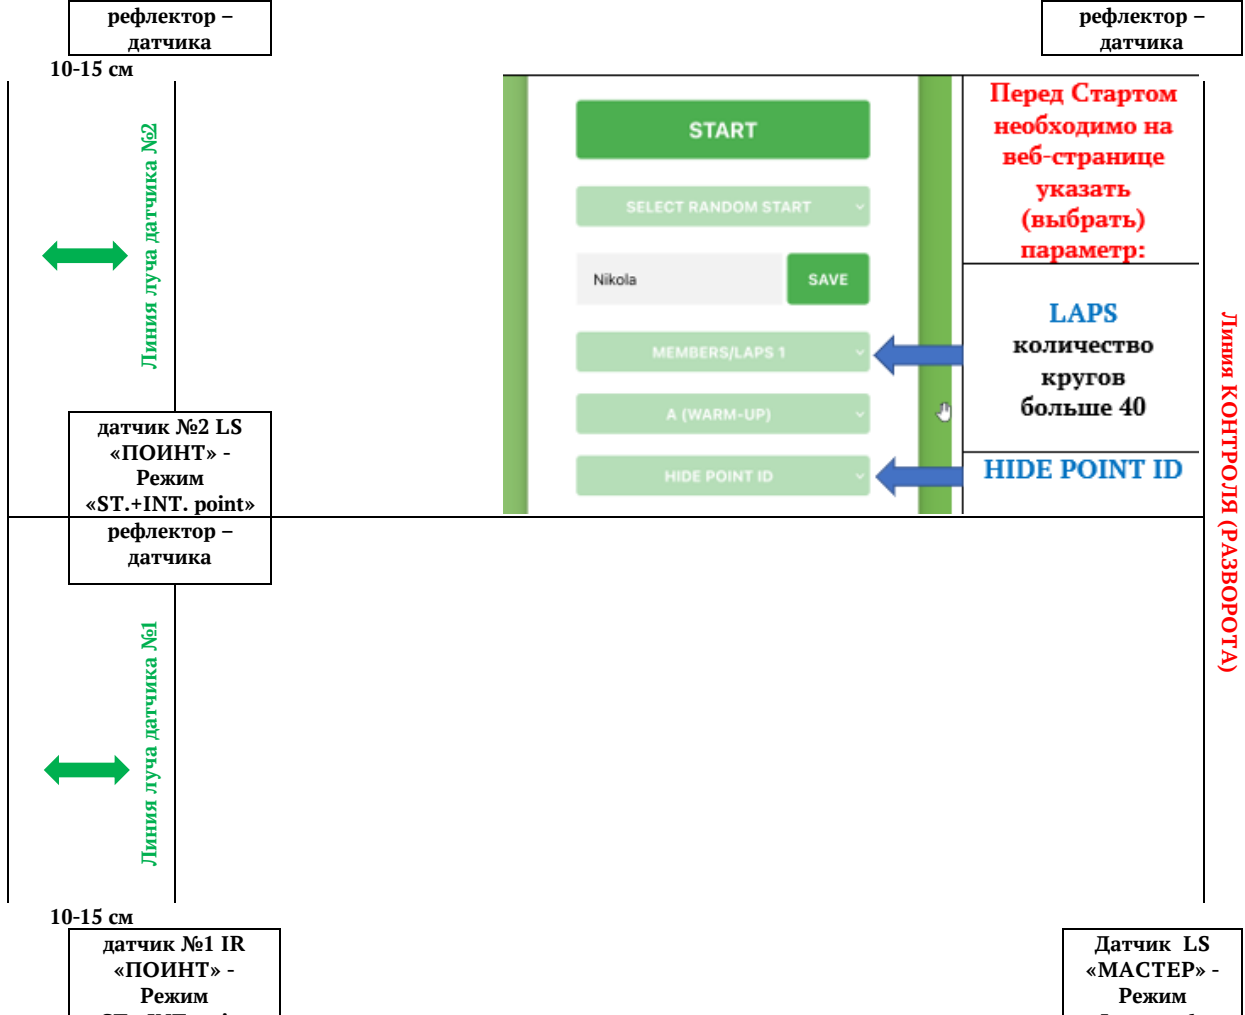
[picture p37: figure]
рефлектор – датчика; Линия луча датчика №2; Линия КОНТРОЛЯ (РАЗВОРОТА); датчик №2 LS «ПОИНТ» - Режим «ST.+INT. point» рефлектор – датчика Линия луча датчика №¹; 10-15 см датчик №1 IR «ПОИНТ» - Режим; Датчик LS «МАСТЕР» - Режим

«ST.+INT. point»
«Laps mode»

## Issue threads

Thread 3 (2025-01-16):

E3Z-LAS-R8

Antonides, 2025-01-16:
Could you please explain how the E3Z-LAS-R8 module (NPN NO) is powered? I understand it requires 12 to 24 V, but I would like more details about the power supply requirements and connection setup.

renat2985, 2025-01-16:
Yes, working with the laser module is more complex.

As an option, you can use a trigger like this one: https://www.aliexpress.com/item/1005005997661443.html

 (Many power supplies can output 12V, 21V, and 5V. If you have such a power supply, you can use it) and get 12V at the output.

Next, use this 12V to power the laser sensor. You will also need a DC-DC Down converter like this one: https://www.aliexpress.com/item/1005005995617482.html which needs to be set to 5V for Wemos or NodeMCU.

Then, the black wire from the laser sensor should be connected to a 10kΩ resistor, and the resistor should be connected to 12V. After that, connect it to a 1N4728A 3.3V zener diode: https://www.aliexpress.com/item/4000297831644.html

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

renat2985, 2025-01-17:
I’d like to share some observations about reflectors. Specifically, this laser. It works great with regular reflective elements on clothing, and in some cases, it performs even better than the standard reflector that comes in the package.

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

https://www.aliexpress.com/item/1005002431496769.html

 This doesn’t apply to IR sensors. For those, large white circular reflectors have shown the best results.

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

I would recommend starting by assembling the device using a standard IR sensor and a Wemos with an ESP-07S. It’s simpler, and the distance between the reflector and the sensor with these white sensors is about 3 meters. Plus, we already have ready-made enclosures for this design.

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

https://www.aliexpress.com/item/1005007081723288.html

renat2985, 2025-01-17:
I drew another diagram. I think it is more successful. The board can be powered from any 5V power bank. :)
https://www.aliexpress.com/item/1005007013856492.html

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

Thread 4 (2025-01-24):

Gate Configuration ( гейт - это стартовые ворота)

renat2985, 2025-01-24:
Для тех кто захочет сделать свой гейт (это стартовые ворота) нарисовал схему, если будут какие-то вопросы, смело общарайтесь.
For those who want to make their own gate (these are the starting gates), I’ve drawn up a diagram. If you have any questions, feel free to reach out.

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

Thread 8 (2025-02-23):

Android APP and NFC tag!

renat2985, 2025-02-23:
Мы разработали мобильное приложение с поддержкой NFC-меток, чтобы упростить запись результатов.
Скачать https://protimer.cub/app.apk

Просто купите NFC-метки (NFC213), используйте приложение для записи имен учеников или спортсменов, приклейте метки на их инвентарь.
Далее все просто — сканируйте метку через приложение, и имя автоматически добавится в таймер!

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

https://www.aliexpress.com/item/1005002932627448.html

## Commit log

2024-11-26 Start :)
    [mirror4.stl, mirror5.stl, schematic.fzz]
2024-11-26 Readme update
    [schematic.fzz]
2024-11-26 Change flasher
    [schematic.fzz, schematic2.fzz]
2024-12-28 Change schematic and AP image
    [mirror3.FCStd, mirror3.stl, mirror4.FCStd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]
2025-01-01 New stl, change on readme
    [box-big.FCStd, box-big.stl, box-small.FCStd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]
2025-01-01 New stl image
2025-01-04 Small fixes on flash page
    [schematic.fzz, schematic2.fzz]
2025-01-06 Update schematic
    [schematic.fzz, schematic2.fzz]
2025-01-07 Schematic bug fix
    [schematic.fzz, schematic2.fzz]
2025-01-15 Add New STL model for wemos and laser sensor
    [box-big-wemos.FCStd, box-big-wemos.stl, сover-laser-microUSB.FCStd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]
2025-01-16 schematic fix
    [schematic.fzz, schematic2.fzz, schematic3.fzz]
2025-01-17 schematic small fix
    [schematic4.fzz]
2025-01-17 Add new link for laser sensor
    [box-big-wemos.FCStd, plug.FCStd, schematic2.fzz]
2025-01-18 Schematic buzzer fix
    [schematic.fzz, schematic2.fzz, schematic3.fzz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]
2025-01-18 Schematic fix final :)
    [box-big-wemos.FCStd, box-big-wemos.stl, display-clips.FCStd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]
2025-01-19 Readme changes
    [schematic2.fzz, schematic3.fzz, schematic4.fzz]
2025-01-19 Schematic button fix
    [schematic.fzz, schematic2.fzz, schematic3.fzz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]
2025-01-24 add Pinout Configuration and gate schematic
    [schematic2_gate.fzz]
2025-02-09 Added support for passive buzzer D6 / GPIO 12
    [box-big-wemos(no hole buzzer).FCStd, box-big-wemos(no hole buzzer).step, box-big-wemos(no hole buzzer).stl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]
2025-02-09 New STL model for wemos
    [box-big-wemos(no hole buzzer).FCStd, box-big-wemos(no hole buzzer).step, box-big-wemos(no hole buzzer).stl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]
2025-02-10 STL add hole
    [box-big-wemos-final-v2.FCStd, box-big-wemos-final-v2.stl, box-big-wemos-final.FCStd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]
2025-02-11 stl mirror add hole
    [mirror3.FCStd, mirror3.stl, mirror4.FCStd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]
2025-02-14 New STL
    [box-big-wemos-final-v2.FCStd, box-big-wemos-final-v3.FCStd, box-big-wemos-final-v3.stl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]
2025-02-25 New Version!
    - The number of members is no longer limited; you can specify the desired amount yourself.
    - A lot of visual effects have been added.
    - When you tap “Delete all timers” in the app, a pop-up message appears asking if you are sure you want to do this.
    - The version is optimized for our mobile application, which includes convenient support for NFC tags.
    [сover-wemos-final-v3.FCStd, сover-wemos-final-v3.stl]
2025-02-27 New Version and new STL for wemos
    - In this version, the design of the story has been updated. Making it more readable, concise, and clear.
    [box-Laser-big-wemos-final-v3.FCStd, box-Laser-big-wemos-final-v3.stl, box-big-wemos-final-v2.FCStd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]
2025-02-28 Add NodeMCU Flasher
    [сover-Laser-P-wemos-final-v3.stl, сover-P-wemos-final-v3.stl]
2025-03-02 New Master version 38
    Each Point device has a unique digital identifier, which can now be displayed along with the time. This allows setting 2 participants in “Members.” We set up two Points by configuring them as “Finish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
2025-03-04 Add link to stl file
2025-03-09 Laser schematic fix
    [box-big-wemos-final-custom.FCStd, box-big-wemos-final-custom.stl, schematic3.fzz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]
2025-04-03 Shematic buzzer fix
    [box-big-final-custom-v2.FCStd, box-big-final-custom-v2.stl, box-big-final-custom.FCStd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]
2025-04-08 New 40 Version
    - Training history is now longer. (By pressing the button on the Master device, you can now view the last 20 entries. Previously, only 5 were displayed.)
    - Renaming of exercise categories. Categories A–G now have clearer and more user-friendly names:
    • A (Warm-up) — Pre-workout warm-up
    • B (Tabata) — Short interval workouts
    • C (HIIT) — High-intensity intervals
    • D (Stretching) — Post-workout stretching
    • E (Rest & Recovery) — Breaks between sets
    • F (Custom 1) — User-defined setting
    • G (Custom 2) — User-defined setting
    [schematic.fzz, schematic2.fzz]
2025-04-21 New design stl file
2025-05-08 New Version and new design by Sekgey K.
    - Added a new design
    - New Laps Mode: set the number of laps, start with random delay, Master acts as the finish (no separate Finish device needed)
    - Improved switching between history pages
    - While the timer is running, you can change exercise letters using the device button
    - Random Start now auto-resets after finish
    - Fullscreen mode: scrolling now works properly
    - Code optimized
2025-05-08 New Version and new design by Sergey K.
    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
2025-11-25 Add PDF instruction.
    [schematic.fzz, schematic2.fzz, schematic5.fzz]
